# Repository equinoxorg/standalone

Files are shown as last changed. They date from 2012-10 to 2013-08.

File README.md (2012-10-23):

#Standalone Designs

##Hardware
This project includes hardware schematics and board layouts for the standalone batterbox (izuba.box) for e.quinox (www.e.quinox.org).

Cadsoft EAGLE is the tool of choice when designing PCBs

###Contents

The following designs are included in this repository

* [Stand_Alone] : The main PCB board controlling payment and outputs
* [Stand_Alone_Inv_Adapter] : The adapter board used in the commercial unit, allows high power loads such as the inverter to be switched. Also provided 2 extra USB outputs and fan contol. Connects the the main boards inverter adapter connector.

##Software

This project includes PIC microcontroller software for the standalone batterbox (izuba.box) for e.quinox (www.e.quinox.org).

The project is MPLAB v1.20. The compiler is the Hi-Tech PIC18 v9.80 Lite C compiler

###Contents

The following designs are included in this repository

* [Stand_Alone] : The main firmware for the standalone units

###Notes
The unlock_code.c file has been deliberatly exluded as it would allow misuse of the payment system. If this is a problem please contact e.quinox.org

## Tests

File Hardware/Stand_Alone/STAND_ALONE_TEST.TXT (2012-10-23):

%
M48
M72
T01C0.0200
T02C0.0240
T03C0.0276
T04C0.0315
T05C0.0320
T06C0.0394
T07C0.0400
T08C0.0433
T09C0.0440
T10C0.0500
T11C0.0512
T12C0.0787
T13C0.0866
%
T01
X14601Y8101
X15101Y7601
X15101Y13601
T02
X18101Y12101
X17601Y10601
X16351Y7351
X14851Y4751
X12601Y7101
X4101Y18601
X27601Y15601
X27601Y10101
X31101Y5101
X32101Y1601
X34101Y1601
T03
X12601Y16601
X11601Y16601
T04
X19101Y7601
X20101Y7601
X20101Y6601
X19101Y6601
X18101Y6601
X17101Y6601
X17101Y3601
X18101Y3601
X19101Y3601
X20101Y3601
X16601Y1951
X14901Y1951
X10782Y5101
X8813Y5101
X30601Y25117
X30601Y27085
T05
X26601Y23801
X26601Y22801
X26601Y20601
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

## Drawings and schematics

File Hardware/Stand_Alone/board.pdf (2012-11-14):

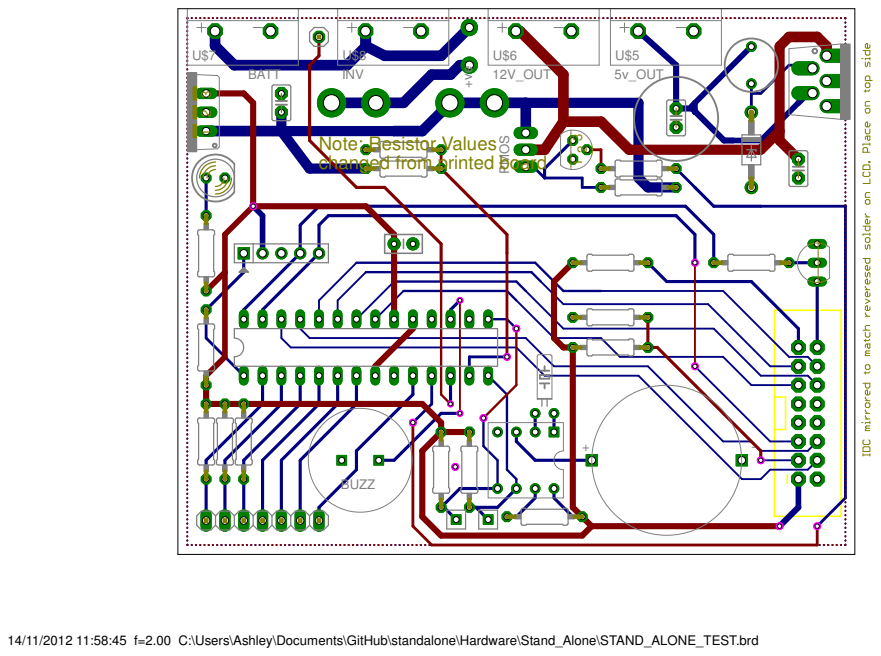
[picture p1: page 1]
BUZZ; PMOS; 5v_OUT; 12V_OUT; BATT; INV

Note: Resistor Values
changed from printed board

14/11/2012 11:58:45 f=2.00 C:\Users\Ashley\Documents\GitHub\standalone\Hardware\Stand_Alone\STAND_ALONE_TEST.brd

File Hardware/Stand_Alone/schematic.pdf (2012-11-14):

Real-time Clock | PIC Microcontroller

A

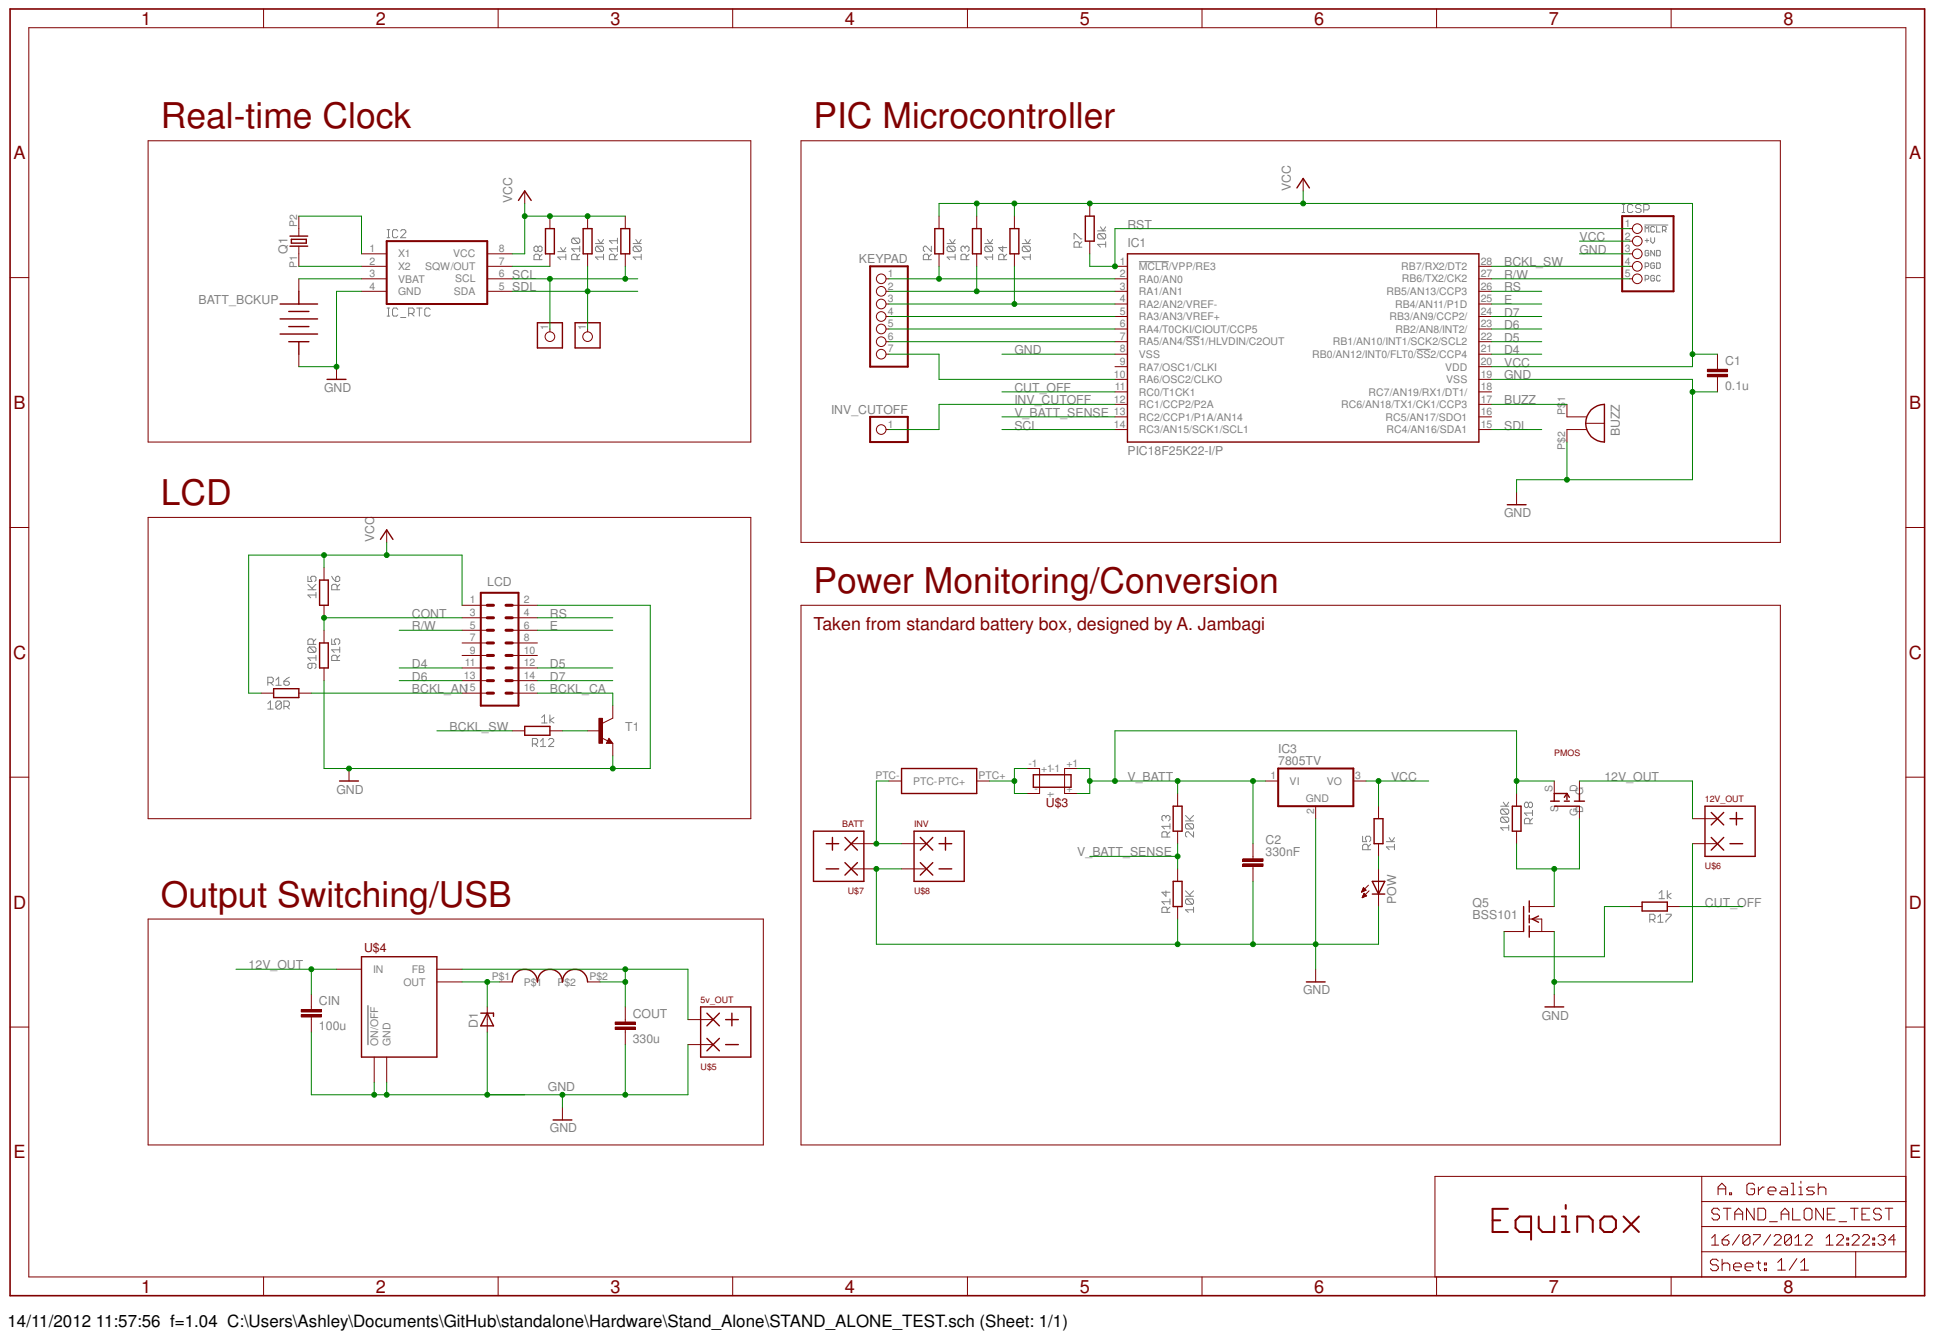
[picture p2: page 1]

Taken from standard battery box, designed by A. Jambagi

14/11/2012 11:57:56 f=1.04 C:\Users\Ashley\Documents\GitHub\standalone\Hardware\Stand_Alone\STAND_ALONE_TEST.sch (Sheet: 1/1)

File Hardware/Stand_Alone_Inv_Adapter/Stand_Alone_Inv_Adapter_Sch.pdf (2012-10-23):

# Standalone Commercial Box Inverter Adapter

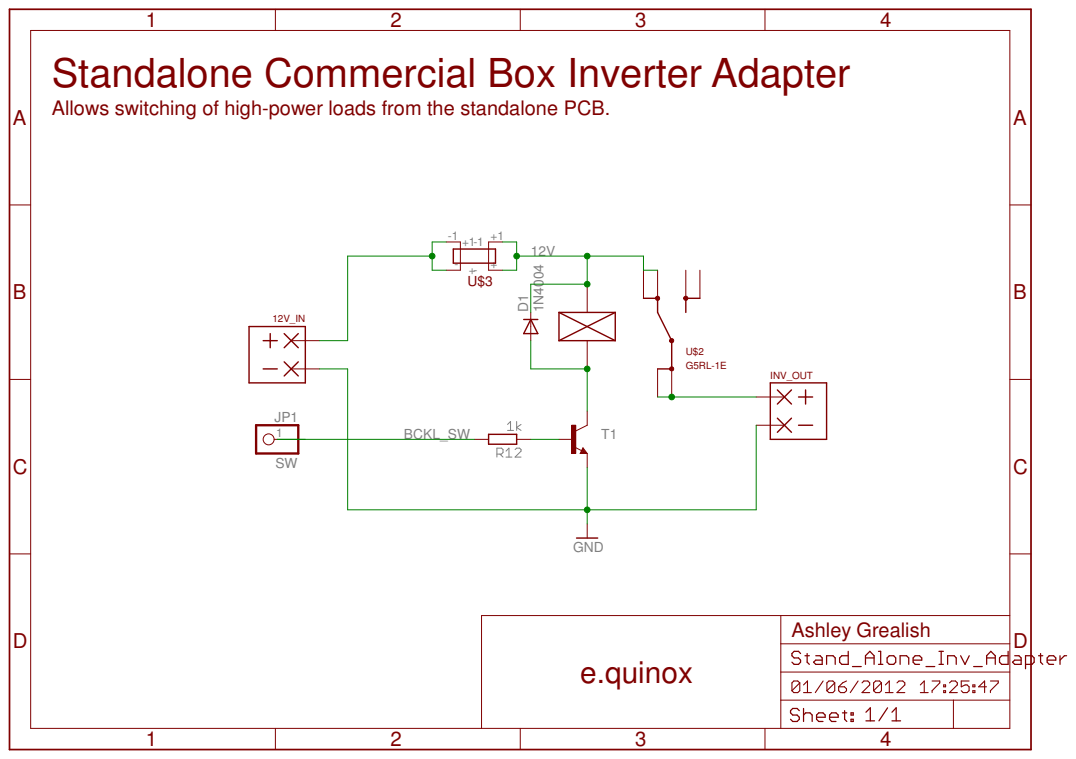
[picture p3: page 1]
GND; BCKL_SW; e.quinox; Ashley Grealish; INV_OUT

Allows switching of high-power loads from the standalone PCB.

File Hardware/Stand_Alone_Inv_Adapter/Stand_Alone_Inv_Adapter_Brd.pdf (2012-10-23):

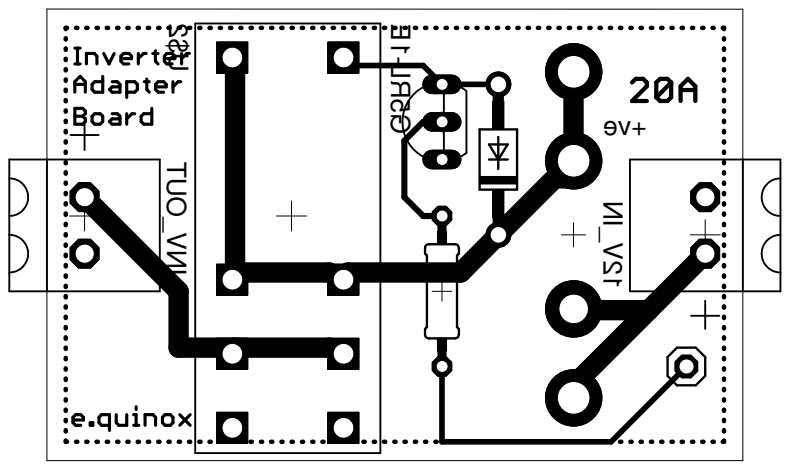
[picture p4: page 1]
INV_OUT

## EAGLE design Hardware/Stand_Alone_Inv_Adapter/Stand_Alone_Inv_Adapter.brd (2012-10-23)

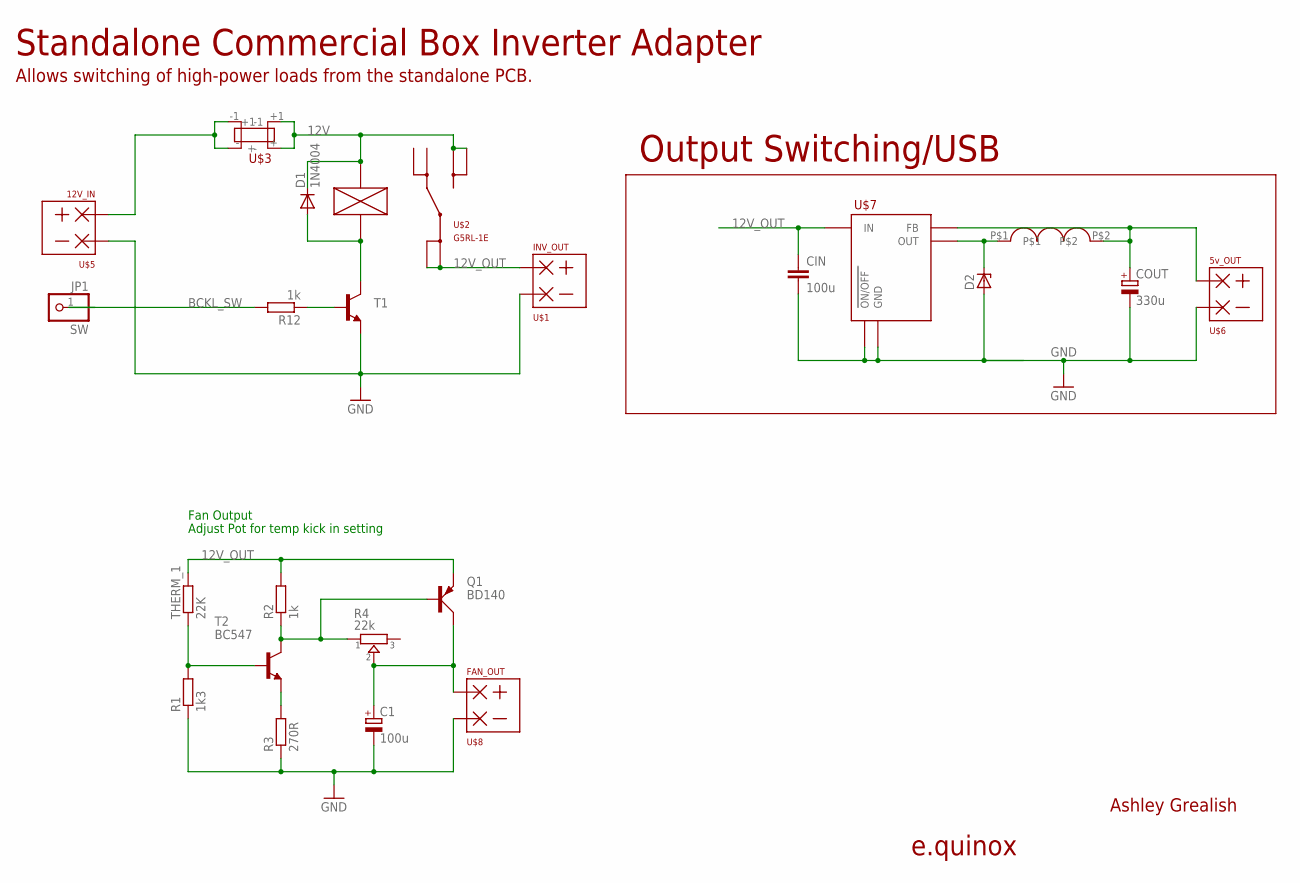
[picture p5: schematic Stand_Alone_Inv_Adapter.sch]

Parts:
C1: 100u; B45181B
CIN: 100u; C2.5-2
COUT: 330u; B45181D
D1: 1N4004; DO41-10
D2: ZENER-DIODEDO41Z10; DO41Z10
JP1: SW; 1X01
Q1: BD140; TO126AV
R1: 1k3; 0207/10
R2: 1k; 0207/10
R3: 270R; 0207/10
R4: 22k; TRIMMER_3362P
R12: 1k; RTH025W
T1: BC546-NPN-TO92-CBE; TO92-CBE
T2: BC547; TO92
THERM_1: 22K; 0204/7
U$1: INV_OUT; TERMINAL_2WAY
U$2: G5RL-1E
U$3: EQBX_FUSEEQBX_FUSE; EQBX_FUSE
U$4: EQBX_INDUCTOR2; INDUCTOR
U$5: 12V_IN; TERMINAL_2WAY
U$6: 5v_OUT; TERMINAL_2WAY
U$7: LM2575; TO220-5
U$8: FAN_OUT; TERMINAL_2WAY

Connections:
12V: D1.C, U$2.COIL+, U$2.NO@1 (NO), U$2.NO@2 (NO), U$3.+, U$3.+1
12V_OUT: CIN.1, Q1.E, R2.2, THERM_1.2, U$1.P$1, U$2.COM@1 (COM), U$2.COM@2 (COM), U$7.P$1 (IN)
BCKL_SW: JP1.1, R12.2
GND: C1.-, CIN.2, COUT.-, D2.A, R1.1, R3.1, T1.E, U$1.P$2, U$5.P$2, U$6.P$2, U$7.P$3 (GND), U$7.P$5 (ON/OFF), U$8.P$2
unnamed: D1.A, T1.C, U$2.COIL-
unnamed: R12.1, T1.B
unnamed: U$3.-, U$3.-1, U$5.P$1
unnamed: R1.2, T2.2 (B), THERM_1.1
unnamed: Q1.B, R2.1, R4.1, T2.3 (C)
unnamed: R3.2, T2.1 (E)
unnamed: C1.+, Q1.C, R4.2, U$8.P$1
unnamed: COUT.+, U$4.P$2, U$6.P$1, U$7.P$4 (FB)
unnamed: D2.C, U$4.P$1, U$7.P$2 (OUT)

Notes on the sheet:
e.quinox
Ashley Grealish
Standalone Commercial Box Inverter Adapter
Allows switching of high-power loads from the standalone PCB.
Output Switching/USB
Fan Output
Adjust Pot for temp kick in setting

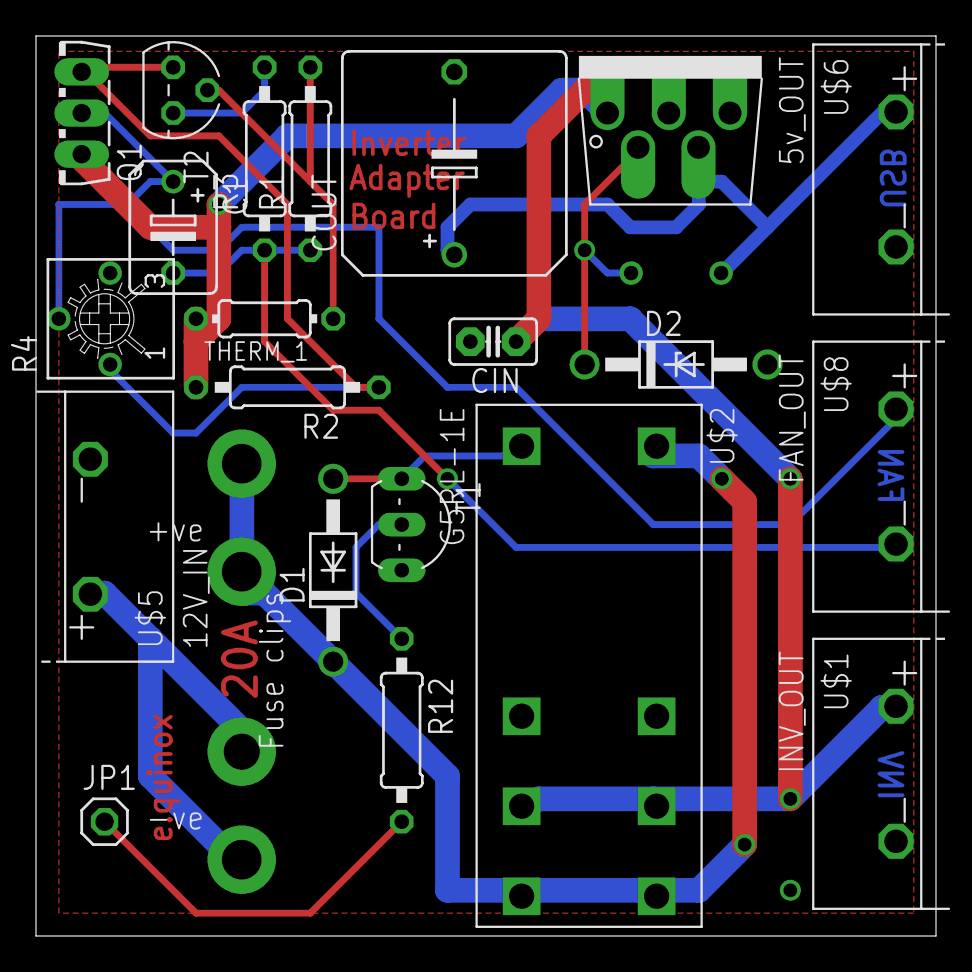
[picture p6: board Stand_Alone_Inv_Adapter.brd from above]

Board: 2 copper layers, 50.0 x 50.0 mm, 23 parts (0 on the bottom side), 13 nets.

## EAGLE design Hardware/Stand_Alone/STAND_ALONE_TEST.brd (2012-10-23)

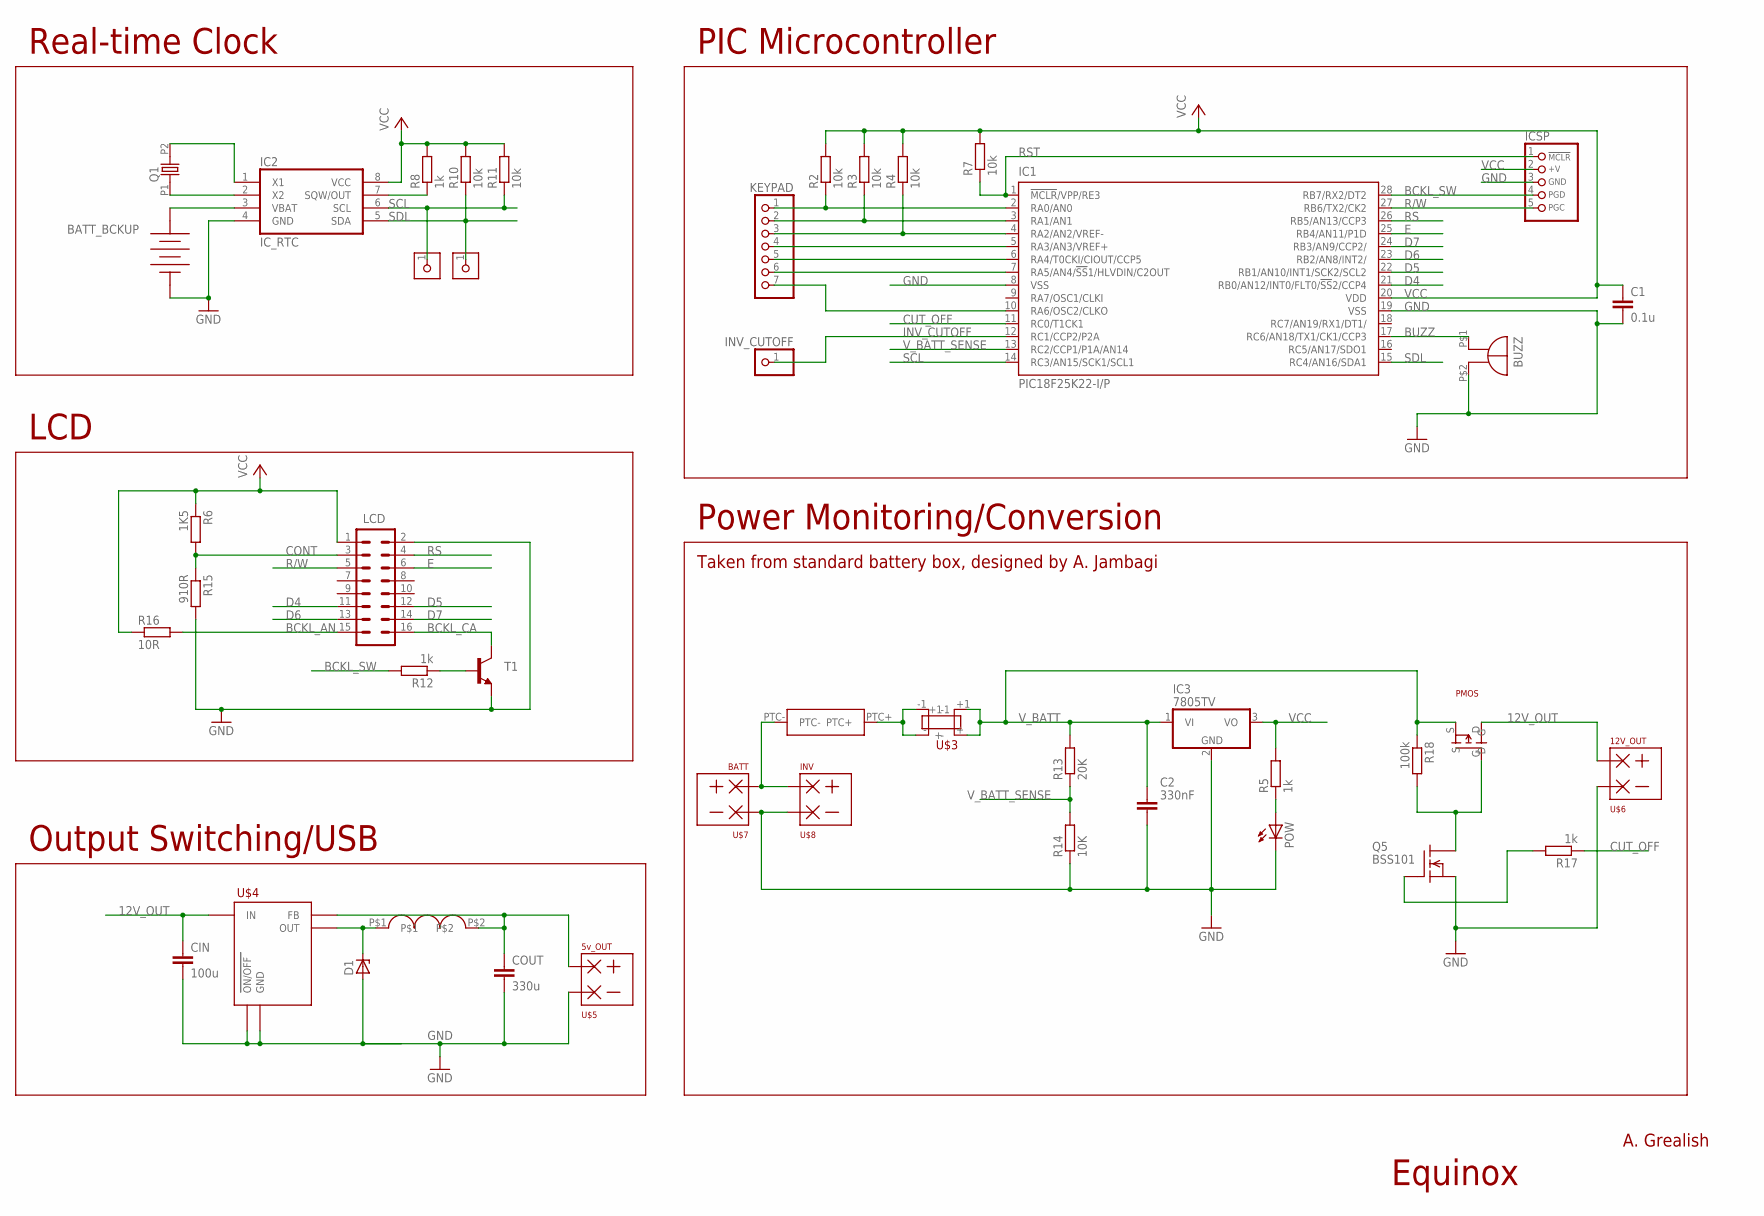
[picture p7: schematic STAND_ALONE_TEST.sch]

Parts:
BATT_BCKUP: RENATA_COIN_CELL; PANASONIC_CR2032_1298246
BUZZ: BUZZ_14MM; 14MM_5M_PINS
C1: 0.1u; CAP-PTH-SMALL2
C2: 330nF; C0.1PTH
CIN: 100u; C2.5-2
COUT: 330u; C2.5-2
D1: ZENER-DIODEDO41Z10; DO41Z10
IC1: PIC18F25K22-I/P; DIP28
IC2: IC_RTC; DIP8
IC3: 7805TV; TO220V
ICSP: CON_HEADER_PRG_PIC_ICSPA; HEADER_PRG_1X05
INV_CUTOFF: PINHD-1X1; 1X01
KEYPAD: PINHD-1X7; 1X07
LCD: M08X2-SHROUDED_LOCK; 2X8-SHROUDED_LOCK
PMOS: PMOS; NMOS_IPAK
POW: LED5MM
Q1: OSC-XTALTC-26; TC-26
Q5: BSS101; TO92
R2, R3, R4, R7, R10, R11: 10k; RTH025W
R5, R8, R12, R17: 1k; RTH025W
R6: 1K5; RTH025W
R13: 20K; RTH025W
R14: 10K; RTH025W
R15: 910R; RTH025W
R16: 10R; RTH025W
R18: 100k; RTH025W
T1: BC546-NPN-TO92-CBE; TO92-CBE
TP_SCL: CON_HEADER_1X01-PTH; M1X1
TP_SDL: CON_HEADER_1X01-PTH; M1X1
U$1: EQBX_INDUCTOR2; INDUCTOR
U$2: EQBX_PTCEQBX_PTC; EQBX_PTC
U$3: EQBX_FUSEEQBX_FUSE; EQBX_FUSE
U$4: LM2575; TO220-5
U$5: 5v_OUT; TERMINAL_2WAY
U$6: 12V_OUT; TERMINAL_2WAY
U$7: BATT; TERMINAL_2WAY
U$8: INV; TERMINAL_2WAY

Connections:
12V_OUT: CIN.1, PMOS.D, U$4.P$1 (IN), U$6.P$1
BCKL_AN: LCD.15, R16.2
BCKL_CA: LCD.16, T1.C
BCKL_SW: IC1.28 (RB7/RX2/DT2), ICSP.4 (PGD), R12.2
BUZZ: BUZZ.P$1 (+), IC1.17 (RC6/AN18/TX1/CK1/CCP3)
CONT: LCD.3, R6.2, R15.1
CUT_OFF: IC1.11 (RC0/T1CK1), R17.1
D4: IC1.21 (RB0/AN12/INT0/FLT0/!SS!2/CCP4), LCD.11
D5: IC1.22 (RB1/AN10/INT1/SCK2/SCL2), LCD.12
D6: IC1.23 (RB2/AN8/INT2/), LCD.13
D7: IC1.24 (RB3/AN9/CCP2/), LCD.14
E: IC1.25 (RB4/AN11/P1D), LCD.6
GND: BATT_BCKUP.P- (NEG), BUZZ.P$2 (-), C1.2, C2.2, CIN.2, COUT.2, D1.A, IC1.8 (VSS), IC1.19 (VSS), IC2.4 (GND), IC3.2 (GND), ICSP.3 (GND), LCD.2, POW.K (C), Q5.1 (S), R14.1, R15.2, T1.E, U$4.P$3 (GND), U$4.P$5 (ON/OFF), U$5.P$2, U$6.P$2, U$7.P$2, U$8.P$2
INV_CUTOFF: IC1.12 (RC1/CCP2/P2A), INV_CUTOFF.1
unnamed: PMOS.G, Q5.3 (D), R18.2
unnamed: R12.1, T1.B
unnamed: U$2.PTC-, U$7.P$1, U$8.P$1
unnamed: IC1.2 (RA0/AN0), KEYPAD.1, R2.1
unnamed: IC1.3 (RA1/AN1), KEYPAD.2, R3.1
unnamed: IC1.4 (RA2/AN2/VREF-), KEYPAD.3, R4.1
unnamed: POW.A, R5.1
unnamed: IC1.5 (RA3/AN3/VREF+), KEYPAD.4
unnamed: IC1.6 (RA4/T0CKI/CIOUT/CCP5), KEYPAD.5
unnamed: IC1.7 (RA5/AN4/!SS!1/HLVDIN/C2OUT), KEYPAD.6
unnamed: IC1.10 (RA6/OSC2/CLKO), KEYPAD.7
unnamed: Q5.2 (G), R17.2
unnamed: IC2.2 (X2), Q1.P1 (1)
unnamed: IC2.1 (X1), Q1.P2 (2)
unnamed: IC2.7 (SQW/OUT), R8.1
unnamed: BATT_BCKUP.P+ (POS), IC2.3 (VBAT)
unnamed: COUT.1, U$1.P$2, U$4.P$4 (FB), U$5.P$1
unnamed: U$2.PTC+, U$3.-, U$3.-1
unnamed: D1.C, U$1.P$1, U$4.P$2 (OUT)
R/W: IC1.27 (RB6/TX2/CK2), ICSP.5 (PGC), LCD.5
RS: IC1.26 (RB5/AN13/CCP3), LCD.4
RST: IC1.1 (!MCLR!/VPP/RE3), ICSP.1 (/MCLR), R7.1
SCL: IC1.14 (RC3/AN15/SCK1/SCL1), IC2.6 (SCL), R11.1, TP_SCL.1
SDL: IC1.15 (RC4/AN16/SDA1), IC2.5 (SDA), R10.1, TP_SDL.1
VCC: C1.1, IC1.20 (VDD), IC2.8 (VCC), IC3.3 (VO), ICSP.2 (+V), LCD.1, R2.2, R3.2, R4.2, R5.2, R6.1, R7.2, R8.2, R10.2, R11.2, R16.1
V_BATT: C2.1, IC3.1 (VI), PMOS.S, R13.2, R18.1, U$3.+, U$3.+1
V_BATT_SENSE: IC1.13 (RC2/CCP1/P1A/AN14), R13.1, R14.2

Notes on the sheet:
Power Monitoring/Conversion
PIC Microcontroller
Real-time Clock
LCD
Output Switching/USB
Taken from standard battery box, designed by A. Jambagi
A. Grealish
Equinox

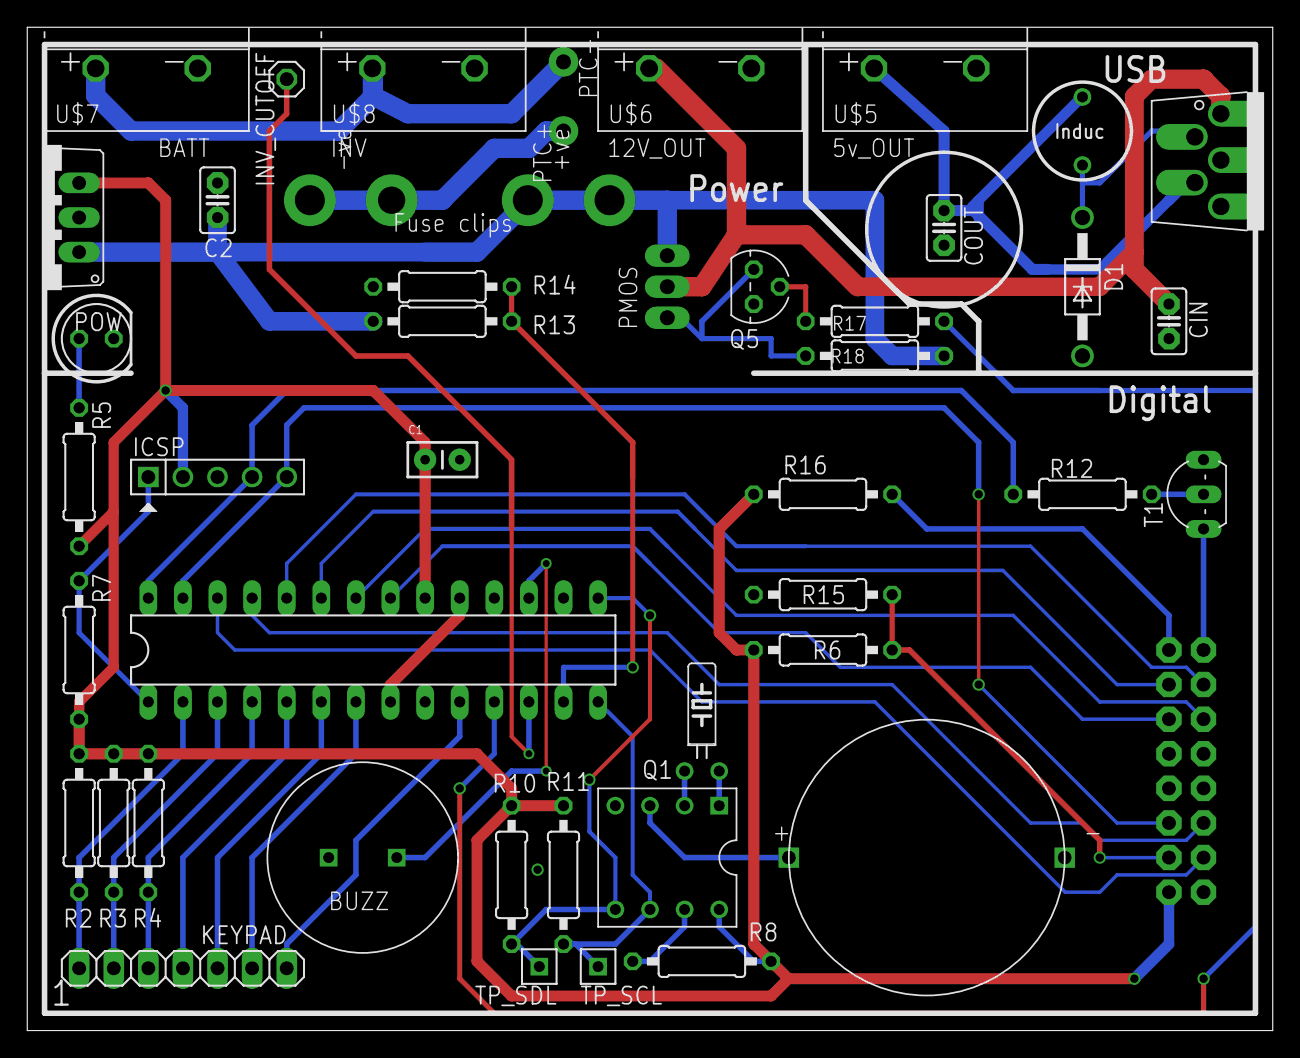
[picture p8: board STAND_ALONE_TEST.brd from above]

Board: 2 copper layers, 91.4 x 73.7 mm, 45 parts (1 on the bottom side), 41 nets.

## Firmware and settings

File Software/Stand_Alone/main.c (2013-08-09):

/********************************************************************

 Firmware for the e.quinox Stand Alone Payment Control Board
---------------------------------------------------------

 * Author: Ashley Grealish
 * Email: ashley.grealish09@imperial.ac.uk
 * Date: June 2012
 * Compiler: HI-TECH C Compiler for PIC18 MCUs (http://www.htsoft.com/)

  
 |  Copyright (C) 2011  Ashley Grealish - e.quinox.org
 |
 |  This program is free software: you can redistribute it and/or modify
 |  it under the terms of the GNU General Public License as published by
 |  the Free Software Foundation, either version 3 of the License, or
 |  (at your option) any later version.
 |
 |  This program is distributed in the hope that it will be useful,
 |  but WITHOUT ANY WARRANTY; without even the implied warranty of
 |  MERCHANTABILITY or FITNESS FOR A PARTICULAR PURPOSE.  See the
 |  GNU General Public License for more details.
 |
 |  You should have received a copy of the GNU General Public License
 |  along with this program.  If not, see <http://www.gnu.org/licenses/>.   
 
 * Functionality:
 * Drives 16x2 LCD Screen
 * Automatic timeput for the LCD backlight to save power
 * Read values from keypad
 * Gives audible feedback for keypad using buzzer
 * Unlocks power outputs for time set by unlock codes
 * RTC moniters the time passed since the last unlock
 * Allows debugging info to be displayed if '1' held on startup
   then 'tick' pressed after the beep
 * Provides countdown to next lock date on LCD screen

 * Todo
 * Clean the keypad read and intToStr conversions
 * Add better switch de-bouncing
 * Change unlock code, to "Next expected unlock code"
 * Add WDT code 
 ********************************************************************/


#ifndef _XTAL_FREQ
#define _XTAL_FREQ  	8000000
#endif

#include <htc.h>
#include <stdint.h>
#include <time.h>

#include "eeprom.h"
#include "LCD.h"
#include "buzz.h"
#include "keypad.h"
#include "unlock_codes.h"
#include "rtc.h"

//IO Ports
#define TEST_LED_RC7	(1<<7)

#define LVCO_PORT   C
#define LVCO_POS    0
#define LVCO_LAT    LATC
#define LVCO_TRIS   TRISC
#define INV_PORT   C
#define INV_POS    1
#define INV_LAT    LATC
#define INV_TRIS   TRISC

#define POWER_OUT_ON()  LVCO_LAT |= (1 << LVCO_POS); INV_LAT |= (1 << INV_POS)
#define POWER_OUT_OFF() LVCO_LAT &= ~(1 << LVCO_POS); INV_LAT &= ~(1 << INV_POS)

#define STATE_NORMAL		0
#define	STATE_AWAIT_PAYMENT	1
#define	STATE_LVCO		2
#define STATE_FULL_UNLOCK       3

#define FULL_BATT_VOLTAGE       (float)14.0
#define CUTOFF_VOLTAGE          (float)10.5
#define VCC_5V_SUPPLY           (float)5.0
#define LOW_BATT_PERCENTAGE     25
#define BATT_TURN_ON_PERCENTAGE 25

#define BACKLIGHT_TIMEOUT       15

#define DAY2SEC     ( (uint32_t)24 * 60 * 60 )
//Debug only
//#define DAY2SEC     ( (uint32_t)10 )

//Function Prototypes
void init_hardware(void);
void Wait(unsigned int);
char check_code(uint32_t);
char *utoa_b(char*, uint32_t, int, uint8_t);
uint8_t get_batt_level(void);
void box_setup(void);
void delay_sec(uint8_t);
void LCDUpdateBattLevel(uint8_t);
void LCDUpdateDaysRem(time_t, time_t);
void debug_display(void);
void update_expiry_date(uint8_t);

//Global variables
char state = STATE_NORMAL;

//------------------------------------------------------------------------------
void main() {
    unsigned char keypad_result, keypad_result_prev;
    char keypad_result_str [10];
    unsigned int i;
    uint8_t digit_count = 0;
    uint32_t entry_code = 0;
    uint8_t batt_level;
    struct tm rtc_time;
    uint16_t backlight_count = 0;

    init_hardware();

    POWER_OUT_OFF();

    //Let the Module start up
    Wait(100);

    //Initialize the LCD Module
    LCDInit(LS_BLINK);

    //Turn on the LCD Backlight
    LCDBacklight_on();

    //Clear the Module
    LCDClear();

    box_setup();
    
    if (!init_rtc()) {
       LCDWriteStringXY(0, 0, "    RTC Error   ");
       delay_sec(1);
    }

    //Check for keypad combination held
    if (read_keypad() == 0x01) {
        buzz(100);
        for (i = 0; i < 200; i++) {
            if (read_keypad() == 0xa1) {
                setup_rtc();
                debug_display();
                break;
            }
            __delay_ms(20);
        }
    }

    // If no WDT timeout (error) occured
    if (RCONbits.TO) {
        //Splash Screen (2s)
        LCDWriteStringXY(0, 0, "    e.quinox    ");
        LCDWriteStringXY(0, 1, "   solar.box    ");
        delay_sec(2);
    }

    //Write Status Info on second line
    LCDWriteStringXY(0, 1, "Batt:___ Days:__");


    //Loop Forever
    while (1) {

        //Case statement implements a state machine.
        //The state is one of four options defined above
        //and stores the overal state of the box
        switch (state) {
            case STATE_NORMAL:
                //Check for Full unlock
                if (ee_read_full_unlock() == EE_FULL_UNLOCK_CODE) {
                    state = STATE_FULL_UNLOCK;
                    LCDWriteStringXY(0, 0, "    e.quinox    ");
                    LCDWriteStringXY(0, 1, "Batt:___        ");
                    backlight_count = 0;
                    break;
                }

                if (read_keypad() != 0xFF) {
                    backlight_count = 0;
                    LCDBacklight_on();
                    buzz(100);
                } else if (backlight_count == BACKLIGHT_TIMEOUT ){
                    LCDBacklight_off();
                } else {
                    backlight_count++;
                }

                //Check Payment
                rtc_get_time_date(&rtc_time);

                LCDUpdateDaysRem(mktime(&rtc_time), ee_read_lock_date());

                if (mktime(&rtc_time) >= ee_read_lock_date()) {
                    state = STATE_AWAIT_PAYMENT;
                    LCDWriteStringXY(0, 0, "Enter:__________");
                    LCDWriteStringXY(0, 1, "Batt:___  Locked");
                    LCDGotoXY(6, 0);
                    backlight_count = 0;
                    break;
                }

                // Battery Level Monitering
                batt_level = get_batt_level();

                if (batt_level == 0)
                    state = STATE_LVCO;
                else
                    LCDUpdateBattLevel(batt_level);

                POWER_OUT_ON();

                //Pauses the box to prevent filckering on screen
                //Update to sleep mode to save power.
                delay_sec(1);

                break;

            case STATE_AWAIT_PAYMENT:

                POWER_OUT_OFF();

                //Read in unlock Code
                keypad_result = read_keypad();

                if ((keypad_result != 0xFF) && (keypad_result != keypad_result_prev)) {
                    backlight_count = 0;
                    LCDBacklight_on();
                    buzz(100);

                    if (keypad_result == 0xa0) {
                        //'X' Pressed
                        //LCDWriteString("x");
                        digit_count = 0;
                        entry_code = 0;
                        LCDWriteStringXY(0, 0, "Enter:__________");
                        LCDWriteStringXY(0, 1, "Batt:___  Locked");
                        LCDGotoXY(6, 0);
                    } else if (keypad_result == 0xa1) {
                        //Tick Pressed
                        //LCDWriteString("./");
                    } else {
                        entry_code = (entry_code * 10) + keypad_result;
                        keypad_result_str[0] = '\0';
                        utoa_b(keypad_result_str, entry_code, 10, digit_count);
                        LCDWriteStringXY(6, 0, keypad_result_str);
                        LCDGotoXY((7 + digit_count), 0);

                        if (digit_count++ == 9) {

                            Wait(1000);

                            digit_count = 0;
                            //Check the unlock code
                            if (check_code(entry_code)) {

                                //Checks if the full unlock code was given
                                if (GET_UNLOCK_DAYS(entry_code) == FULL_UNLOCK) {
                                    ee_write_full_unlock(EE_FULL_UNLOCK_CODE);
                                    state = STATE_FULL_UNLOCK;
                                    LCDWriteStringXY(0, 0, "    e.quinox    ");
                                    LCDWriteStringXY(0, 1, "Batt:___        ");
                                    backlight_count = 0;
                                    break;
                                }

                                //Updates the next unlock code expiry date
                                update_expiry_date(GET_UNLOCK_DAYS(entry_code));

                                //Updates state
                                state = STATE_NORMAL;
                                //Reset the entry code for next code entry
                                entry_code = 0;
                                LCDWriteStringXY(0, 0, "    e.quinox    ");
                                LCDWriteStringXY(0, 1, "Batt:___ Days:__");
                                break;

                            } else {
                                LCDWriteStringXY(0, 0, "    Incorrect   ");
                                LCDWriteStringXY(0, 1, "Enter valid code");
                                delay_sec(5);
                                LCDWriteStringXY(0, 0, "Enter:__________");
                                LCDWriteStringXY(0, 1, "Batt:___ Days:__");
                                LCDGotoXY(6, 0);
                            }
                            entry_code = 0;
                        }
                    }

                } else if (backlight_count == (BACKLIGHT_TIMEOUT*100) ){
                    LCDBacklight_off();
                } else {
                    backlight_count++;
                }

                keypad_result_prev = keypad_result;

                //Debouncing time
                Wait(50);


                // Battery Level Monitering
                batt_level = get_batt_level();

                if (batt_level == 0)
                    state = STATE_LVCO;
                else
                    LCDUpdateBattLevel(batt_level);

                break;

            case STATE_LVCO:
                POWER_OUT_OFF();
                LCDWriteStringXY(0, 0, "  Turn off and  ");
                LCDWriteStringXY(0, 1, "    Recharge!   ");

                // Battery Level Monitering
                if (get_batt_level() >= BATT_TURN_ON_PERCENTAGE) {
                    if (ee_read_full_unlock() == EE_FULL_UNLOCK_CODE) {
                        state = STATE_FULL_UNLOCK;
                        LCDWriteStringXY(0, 0, "    e.quinox    ");
                        LCDWriteStringXY(0, 1, "Batt:___        ");
                        break;
                    } else {
                        state = STATE_NORMAL;
                        LCDWriteStringXY(0, 0, "    e.quinox    ");
                        LCDWriteStringXY(0, 1, "Batt:___ Days:__");
                        break;
                    }
                }

                buzz(100);
                delay_sec(1);

                break;
            case STATE_FULL_UNLOCK:

                POWER_OUT_ON();

                // Battery Level Monitering
                batt_level = get_batt_level();

                if (batt_level == 0) {
                    state = STATE_LVCO;
                    break;
                } else {
                    LCDUpdateBattLevel(batt_level);
                }

                if (read_keypad() != 0xFF) {
                    backlight_count = 0;
                    LCDBacklight_on();
                    buzz(100);
                } else if (backlight_count == BACKLIGHT_TIMEOUT ){
                    LCDBacklight_off();
                } else {
                    backlight_count++;
                }

                delay_sec(1);

                break;
        }
    }

}

//------------------------------------------------------------------------------
void delay_sec(uint8_t seconds) {
    unsigned int i;

    for (i = 0; i < (100 * seconds); i++)
        __delay_ms(10);
}

//------------------------------------------------------------------------------
//------------------------------------------------------------------------------
void box_setup() {
    uint16_t box_id;
    uint8_t i, keypad_result;
    uint8_t keypad_result_prev = 0xFF;
    uint8_t count_i;

    box_id = ee_read_box_id();




    if ((box_id == 0) || (box_id == 0xFFFF)) {

        POWER_OUT_ON();


        LCDWriteStringXY(0, 0, "Box_ID:")

        for (i = 0; i < 5; i++) {
            do {
                //Read in box_id
                keypad_result = read_keypad();
                if (keypad_result == 0xFF)
                    keypad_result_prev = 0xFF;
                //Debouncing time
                Wait(50);
            } while ((keypad_result == 0xFF) || (keypad_result == keypad_result_prev));

            buzz(100);
            if (keypad_result == 0xa0) {
                //tick Pressed
            } else if (keypad_result == 0xa1) {
                //cross pressed
                box_id = 0;
                i = 0;
            } else {
                box_id = (box_id * 10) + keypad_result;
                LCDWriteIntXY(7, 0, box_id, (i + 1));
            }

            keypad_result_prev = keypad_result;

        }
        
        ee_write_box_id(box_id);


        count_i = ee_read_unlock_count();

    if ((count_i == 0) || (count_i == 0xFF)) {


        LCDWriteStringXY(0, 0, "Unlock_count:")

       for (i = 0; i < 2; i++) {
            do {
                //Read in unlock_count
                keypad_result = read_keypad();
                if (keypad_result == 0xFF)
                    keypad_result_prev = 0xFF;
                //Debouncing time
                Wait(50);
            } while ((keypad_result == 0xFF) || (keypad_result == keypad_result_prev));

            buzz(100);
            if (keypad_result == 0xa0) {
                //tick Pressed
            } else if (keypad_result == 0xa1) {
                //cross pressed
                count_i = 0;
                i = 0;
            } else {
                count_i = (count_i * 10) + keypad_result;
                LCDWriteIntXY(14, 0, count_i, (i + 1));
            }

            keypad_result_prev = keypad_result;

        }

        ee_write_unlock_count(count_i);
        
        LCDClear();
        LCDWriteStringXY(0, 0, "Box_ID_Verify:");
        LCDWriteIntXY(0, 1, ee_read_box_id(), 5);
        delay_sec(3);
        LCDClear();
    }

        setup_rtc();

        debug_display();

        POWER_OUT_OFF();

    }

    // if (ee_read_unlock_count() == 0xFF)
      //  ee_write_unlock_count(0x00);

    //Set the box ID
    set_box_id(box_id);



}
//------------------------------------------------------------------------------
char check_code(uint32_t code) {
    char code_valid = 0;
    uint8_t unlock_count = ee_read_unlock_count();

    if (check_checksum(code)) {
        if (((GET_UNLOCK_COUNT(code) - unlock_count) <= 1) || (GET_UNLOCK_DAYS(code) == FULL_UNLOCK)) {
            ee_write_unlock_count(GET_UNLOCK_COUNT(code) + 1);
            code_valid = 1;
        }
    }

    return code_valid;
}

//------------------------------------------------------------------------------
char *utoa_b(char *buf, uint32_t val, int base, uint8_t pad) {
    uint32_t v;
    char c;
    int i = 0;

    v = val;
    do {
        v /= base;
        buf++;
    } while (i++ != pad);
    *buf-- = 0;
    i = 0;
    do {
        c = val % base;
        val /= base;
        if (c >= 10)
            c += 'A' - '0' - 10;
        c += '0';
        *buf-- = c;
    } while (i++ != pad);
    return buf;
}

//------------------------------------------------------------------------------
//Simple Delay Routine
void Wait(unsigned int delay) {
    for (; delay; delay--)
        __delay_us(100);
}

//------------------------------------------------------------------------------
void init_hardware() {

    //8Mhz Clock
    OSCCON &= 0b11101111;
    OSCCON |= 0b01100000;

    //A register is keypad
    //Sets up all pins as digital inputs
    //One-hot switching to outputs in keypad_read() function
    TRISA = 0xFF;
    ANSELA = 0x00;

    //B port used for LCD comms
    //Sets up all pins as digital inputs
    TRISB = 0xFF;
    ANSELB = 0x00;

    //Port C used for I2c bus and misc outputs
    //Buzzer is output
    TRISC = ~TEST_LED_RC7;
    //Set up Analogue in on RC2/AN14
    ANSELC = (1 << 2);
    //Disables PWM output on RC0
    CCP1CON = 0;
    CCP2CON = 0;
    T1CON &= ~0b11000000;
    T3CON &= ~0b11000000;

    //Make LVCO pin an output
    LVCO_TRIS &= ~(1 << LVCO_POS);

    INV_TRIS &= ~(1 << INV_POS);

    init_buzz();
}

//------------------------------------------------------------------------------
void LCDUpdateBattLevel(uint8_t batt_level) {
    if (batt_level == 100) {
        LCDWriteStringXY(0, 1, "Batt:100%");
    } else if (batt_level < LOW_BATT_PERCENTAGE) {
        //low_voltage_indicator = 1;
        LCDWriteStringXY(0, 1, "Low Batt ");
    } else {
        //Go to battery level location
        LCDWriteStringXY(0, 1, "Batt:");
        LCDWriteInt(batt_level, 2);
        LCDWriteString("% ");
        //LCDBacklight_on();
    }
    LCDGotoXY(17, 0);

}

//------------------------------------------------------------------------------
uint8_t get_batt_level(void) {
    int i;
    uint16_t adc_result = 0;
    float adc_result_float, batt_voltage;

    //ADC Channel Select AN14
    ADCON0 = 0b00111000;
    //Turn on ADC
    ADCON0 |= 0b00000001;

    //Right justified, longest aqu time, fasted clock
    //Needs work
    ADCON2 = 0b10111000;

    for (i = 0; i < 8; i++) {
        //Start the conversion
        ADCON0 |= 0b00000010;

        //Wait for conversion to finish
        while (ADCON0 & 0b00000010);

        adc_result += (((uint16_t) ADRESH << 8) | ADRESL);
    }

    //adc_result div 8
    adc_result_float = (float) adc_result / 8.0;

    batt_voltage = ((float) (VCC_5V_SUPPLY * 3) / 1024.0) * adc_result_float;

    if (batt_voltage < CUTOFF_VOLTAGE) {
        return 0;
        //Error
    } else if (batt_voltage > FULL_BATT_VOLTAGE) {
        return 100;
    } else {
        return (uint8_t) (((batt_voltage - CUTOFF_VOLTAGE) / (FULL_BATT_VOLTAGE - CUTOFF_VOLTAGE)) * 100);
    }
}

//------------------------------------------------------------------------------
void LCDUpdateDaysRem(time_t current_time, time_t unlock_time) {
    uint8_t days_rem;

    if (current_time > unlock_time) {
        LCDWriteStringXY(9, 1, "_Locked");
    } else {
        days_rem = (uint8_t) ((float) (unlock_time - current_time) / (float) (DAY2SEC));
        LCDWriteIntXY(14, 1, days_rem, 2);
    }
}

//------------------------------------------------------------------------------
void debug_display(void) {
    struct tm rtc_time;
    unsigned char j;
    uint32_t temp_32;

    //debug mode
    LCDWriteStringXY(0, 0, "Unlock Count:");
    LCDWriteIntXY(0, 1, ee_read_unlock_count(), 3);
    delay_sec(3);
    LCDClear();
    LCDWriteStringXY(0, 0, "Box_ID:");
    LCDWriteInt(ee_read_box_id(), 5);
    delay_sec(3);
    LCDClear();
    if (ee_read_full_unlock() == EE_FULL_UNLOCK_CODE) {
        LCDWriteString("Full Unlock");
    } else {
        LCDWriteString("Not Full Unlock");
    }
    delay_sec(3);

    for (j = 0; j < 100; j++) {

        //RTC Clock Test
        rtc_get_time_date(&rtc_time);
        temp_32 = mktime(&rtc_time);
        LCDClear();
        LCDGotoXY(0, 0);
        LCDWriteInt(rtc_time.tm_mday, 2);
        LCDWriteString("/");
        LCDWriteInt(rtc_time.tm_mon, 2);
        LCDWriteString("/");
        LCDWriteInt((uint16_t) ((uint16_t) rtc_time.tm_year + (uint16_t) 1900), 4);
        LCDGotoXY(0, 1);
        LCDWriteInt(rtc_time.tm_hour, 2);
        LCDWriteString(":");
        LCDWriteInt(rtc_time.tm_min, 2);
        LCDWriteString(":");
        LCDWriteInt(rtc_time.tm_sec, 2);
        __delay_ms(20);
    }
}

//------------------------------------------------------------------------------
void update_expiry_date(uint8_t unlock_time_code) {

    time_t unlock_time_sec = 0;
    time_t unlock_time = 0;
    struct tm rtc_time;

    LCDClear();

    switch (unlock_time_code) {
        case FULL_UNLOCK:
            unlock_time = 0xFFFFFFFF;
            LCDWriteString("   Full Unlock  ");
            break;
        case TWO_DAYS:
            unlock_time = (2 * DAY2SEC);
            LCDWriteString("     2 Days     ");
            break;
        case FIVE_DAYS:
            unlock_time = (5 * DAY2SEC);
            LCDWriteString("     5 Days     ");
            break;
        case SEVEN_DAYS:
            unlock_time = (7 * DAY2SEC);
            LCDWriteString("    7 Days      ");
            break;
        case TWO_WEEKS:
            unlock_time = (14 * DAY2SEC);
            LCDWriteString("    2 Weeks     ");
            break;
        case THREE_WEEKS:
            unlock_time = (21 * DAY2SEC);
            LCDWriteString("     3 Weeks    ");
            break;
        case ONE_MONTH:
            unlock_time = (28 * DAY2SEC);
            LCDWriteString("    4 Weeks     ");
            break;
        case TWO_MONTHS:
            unlock_time = (56 * DAY2SEC);
            LCDWriteString("     8 Weeks    ");
            break;
        default:
            unlock_time = 0;
            LCDWriteString("      Error     ");
    }

    //Write RTC + unlock time to expire date eeprom
    rtc_get_time_date(&rtc_time);
    unlock_time_sec = mktime(&rtc_time) + (time_t) unlock_time;
    ee_write_lock_date(unlock_time_sec);

    delay_sec(3);
}

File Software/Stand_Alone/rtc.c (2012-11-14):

/*
 
 |  Copyright (C) 2011  Ashley Grealish - e.quinox.org
 |
 |  This program is free software: you can redistribute it and/or modify
 |  it under the terms of the GNU General Public License as published by
 |  the Free Software Foundation, either version 3 of the License, or
 |  (at your option) any later version.
 |
 |  This program is distributed in the hope that it will be useful,
 |  but WITHOUT ANY WARRANTY; without even the implied warranty of
 |  MERCHANTABILITY or FITNESS FOR A PARTICULAR PURPOSE.  See the
 |  GNU General Public License for more details.
 |
 |  You should have received a copy of the GNU General Public License
 |  along with this program.  If not, see <http://www.gnu.org/licenses/>.   
*/

#include "rtc.h"


#define I2C_SLAVE 0b1101000                    // Slave device I2C address

#define I2C_WRITE 0
#define I2C_READ 1

// Send a command to servo ic
void rtc_word_write(unsigned char address, unsigned char data)
{
    i2c_Start();                        // send Start
    i2c_Address(I2C_SLAVE, I2C_WRITE);  // Send slave address - write operation
    i2c_Write(address);	                // Address of data
    i2c_Write(data);	                // send data
    i2c_Stop();	                        // send Stop
}

// Read a char from servo ic
unsigned char rtc_word_read(unsigned char address)
{
    unsigned char read_byte;
    // Read one byte (i.e. servo pos of one servo)
    i2c_Start();                        // send Start
    i2c_Address(I2C_SLAVE, I2C_WRITE);  // Send slave address - write operation
    i2c_Write(address);	                // Address of read location
    i2c_Restart();                      // Restart
    i2c_Address(I2C_SLAVE, I2C_READ);   // Send slave address - read operation
    read_byte = i2c_Read(0);            // Read one byte
                          // If more than one byte to be read, (0) should
                          // be on last byte only
                          // e.g.3 bytes= i2c_Read(1); i2c_Read(1); i2c_Read(0);
    i2c_Stop();                         // send Stop
    return read_byte;                   // return byte.
                                        // If reading more than one byte
                                        // store in an array
}

void rtc_time_date_read ( uint8_t* data_array ) {
    
    uint8_t i;

    i2c_Start();                        // send Start
    i2c_Address(I2C_SLAVE, I2C_WRITE);  // Send slave address - write operation
    i2c_Write(0x00);	                // Send start address
    i2c_Restart();                      // Restart
    i2c_Address(I2C_SLAVE, I2C_READ);   // Send slave address - read operation
    for (i = 0; i < 6; i++) {
        data_array[i] = i2c_Read(1);
    }
    data_array[6] = i2c_Read(0);
    i2c_Stop();
}

uint8_t bcd_to_uint8 (uint8_t in_data){
    return ( (in_data & 0x0F) + (((in_data >> 4 ) & 0x0F)*10) );
}

void rtc_get_time_date( struct tm* time_ptr ){
    uint8_t rtc_mem_array[7];

    rtc_time_date_read(&rtc_mem_array);

    time_ptr->tm_sec = bcd_to_uint8(rtc_mem_array[0] & 0b01111111);
    time_ptr->tm_min = bcd_to_uint8(rtc_mem_array[1]);
    time_ptr->tm_hour = bcd_to_uint8(rtc_mem_array[2] & 0b00111111);
    time_ptr->tm_mday = bcd_to_uint8(rtc_mem_array[4]);
    time_ptr->tm_mon = bcd_to_uint8(rtc_mem_array[5]);
    time_ptr->tm_year =  (bcd_to_uint8(rtc_mem_array[6]) + 70);

    mktime(time_ptr);

}

uint8_t rtc_get_sec (void) {
    uint8_t register_val, seconds;

    register_val = rtc_word_read(0x00); 

    seconds = register_val & 0b00001111;
    seconds += ((register_val & 0b01110000) >> 4) * 10;

    return seconds;

}


uint8_t rtc_get_min (void) {
    uint8_t register_val, mins;

    register_val = rtc_word_read(0x01); 

    mins = register_val & 0b00001111;
    mins += ((register_val & 0b01110000) >> 4) * 10;

    return mins;

}

uint8_t rtc_get_hour (void) {
    uint8_t register_val, hour;

    register_val = rtc_word_read(0x02); 

    hour = register_val & 0b00001111;
    hour += ((register_val & 0b00110000) >> 4) * 10;

    return hour;

}

uint8_t rtc_get_date (void) {
    uint8_t register_val, date;

    register_val = rtc_word_read(0x04); 

    date = register_val & 0b00001111;
    date += ((register_val & 0b00110000) >> 4) * 10;

    return date;

}

uint8_t rtc_get_month (void) {
    uint8_t register_val, month;

    register_val = rtc_word_read(0x05); 

    month = register_val & 0b00001111;
    month += ((register_val & 0b00010000) >> 4) * 10;

    return month;

}

uint16_t rtc_get_year (void) {
    uint16_t register_val, year;

    register_val = rtc_word_read(0x06); 

    year = register_val & 0b00001111;
    year += ((register_val & 0b11110000) >> 4) * 10;

    return year + 1970;
}

uint32_t time_since_epoch (void) {
    time_t epoch_time;
    struct tm time_s;

    //read_struct_tm( &time_s );
    rtc_get_time_date( &time_s );

    epoch_time = mktime( &time_s );

    return epoch_time;
}


unsigned char init_rtc(void) {
   
    i2c_Init(); // Start I2C as Master 100KHz

    //Checks that the rtc is turned on, if not returns non-zero number
    return rtc_word_read(0x00) & ~0b1000000;
}

void setup_rtc(void) {

    i2c_Init(); // Start I2C as Master 100KHz

    // Set the control register
    rtc_word_write(0x07, 0b00000000);
    //Turns the clock on
    rtc_word_write(0x00, 0x00);//, (rtc_word_read(0x00) & ~0b1000000) );
    //Turns on 24h mode
    rtc_word_write(0x02, (rtc_word_read(0x02) & ~0b0100000));
}

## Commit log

2012-10-23 First Commit
    Design files for the first version of the standalone system. Deployed in
    2012 in Minazi
    [STAND_ALONE_TEST.brd, STAND_ALONE_TEST.sch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]
2012-11-14 Added PDFs of Schematic and board
